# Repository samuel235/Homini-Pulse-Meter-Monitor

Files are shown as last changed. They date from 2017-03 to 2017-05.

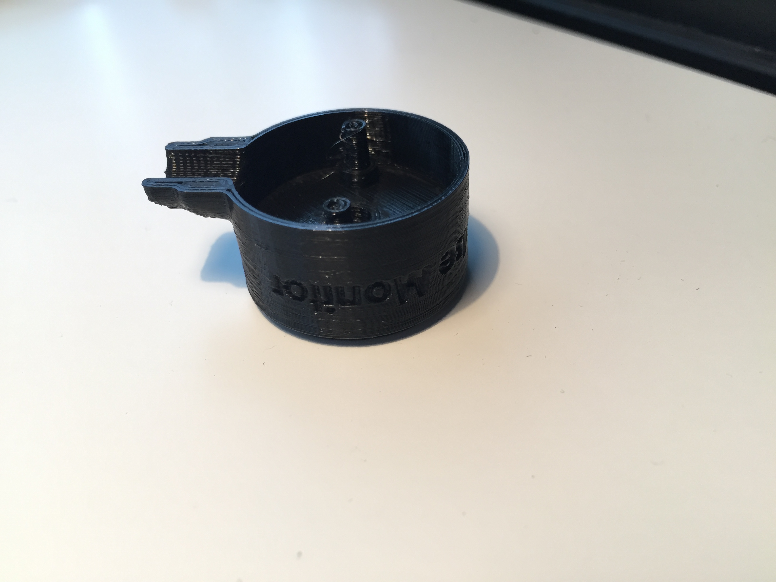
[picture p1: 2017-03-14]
sensor/images/3.jpeg

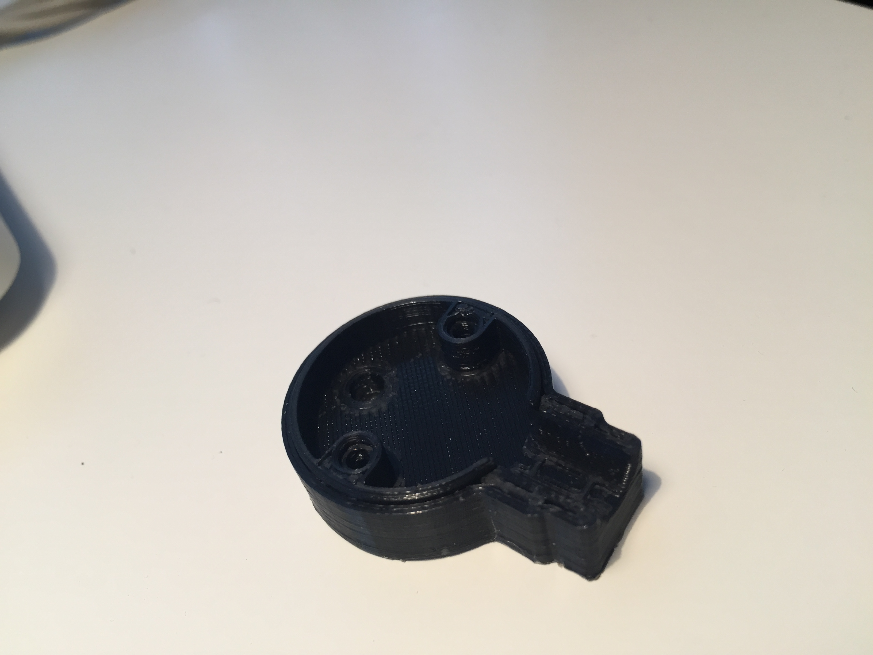
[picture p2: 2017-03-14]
sensor/images/1.jpeg

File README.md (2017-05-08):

# Homini Pulse Meter Monitor

## Brief Description
This ATMEGA328P based board has been created to enable wireless monitoring of your power meter. The product comprises of two parts, one sensor attachment and one custom ATMEGA328P board that the sensor connects to. Both parts are enclosed inside of their own 3D printed enclosures to ensure safety to the devices.

This device has been designed to be located directly on your power meter, the sensor is stuck to the front and the controller is enclosed off to the side of the meter, designed to stick to the side also with Velcro, but you can put it where you wish. The sensor module is attached to the Controller device via a micro USB connector but obviously this can be modified to suit your personal needs.

There is a footprint to allow the use of a AT25DF512C Flash IC to allow the use of OTA updates with MYSBootloader, please refer to the MYSBootloader documentation for the use of this feature to discover the needed fuses and process to install MYSBootloader itself. This enables you the option of updating the device for future software updates without physically getting to the device. We have also allowed the use of a ATSHA204 hardware signing by including a footprint for the ATSHA204 IC on the controller board.

## Function
- To monitor power usage of your home and report back to controller software for a visible display of your consumed electricity.

## Physical Dimensions
- Sensor: 36mm x 24mm x 33mm (Width x Length x Height)
- Controller: TBA

## Connectors
- FTDI and SPI for firmware upgrades
- Micro USB for Powering the device
- Micro USB for sensor connection

## Connections
#### Radio Frequency
Footprints for the following radios will be included.
- nRF24L01 Radio Transceiver
- RFM69 Radio Transceiver

## Power Supply
##### Either of the following:
- Micro USB wall charger.
- CR2450 Coin-cell battery.

## Software
#### Bootloader
- Mains Powered: [Gertsanders' bootloader](https://www.mysensors.org/about/bootloader) running at 16MHz External crystal.
- Battery Powered: [Gertsanders' bootloader](https://www.mysensors.org/about/bootloader) running at 8MHz Internal or External crystal.

If you would like to use OTA updates then please use [MYSBootloader](https://www.mysensors.org/about/ota)

#### Sketch

Will update sketches once I receive PCBs to test different variants of software out:

[Generic pulse sensor sketch Located here](https://www.mysensors.org/build/pulse_power), alternatively you can find customised sketches on my [github](https://github.com/samuel235/Homini-Pulse-Meter-Monitor) inside of the relevant folder to your build type.

## Testing
Testing will commence once boards have been received and assembled.

1. Controller board - Mains powered version - **COMPLETED**
2. Sensor board - Mains powered version - **COMPLETED**

## TO-DO List
1. Add battery monitoring circuitry for next version

## Update Log:
- Micro-Controller board designed (25/03/17)
- Sensor board designed (15/03/17)
- Sensor board (battery) designed (06/04/17)
- All boards ordered using [PCBWay](www.pcbway.com) (10/04/17)
- Board arrived and testing commenced (26/04/17)

## Issues
1. No issues reported at current date.

## Appreciations
Special thanks to:
1. Scalz from the MySensors community that has provided relevant design files and circuit schematics to aid in this product design. [MySensors](https://forum.mysensors.org/user/scalz)/[github](https://github.com/scalz)
2. [Mysensors.org](Mysensors.org)
3. [Openhardware.org](Openhardware.org)
4. [Sparkfun](sparkfun.com) and [Adafruit](adafruit.com) for their parts library for Eagle

If you have any suggestions, please add to the forum post over at [MySensors forum post](https://forum.mysensors.org/topic/6460/homini-pulse-meter-monitor)

I'm very interested in all of your variations, improvements and applications of this module, please add them to the comments with pictures and/or Videos.

## Disclaimer
**_I do not advise you in any way to make/install this product into a property and therefore I take no responsibility for any issues, problems you have or even health implications that you endure while completing the installation or even using the product after installing. BUILD, USE and INSTALL AT YOUR OWN RISK_**

## Licensing
This product is licensed under the CC-BY-SA OpenHardware certificate. For more information please see https://creativecommons.org/licenses/by-sa/4.0/

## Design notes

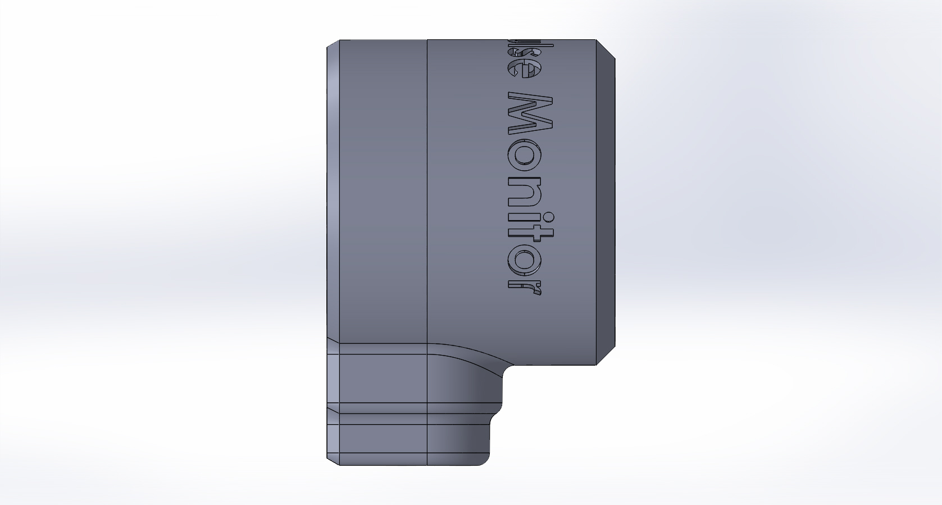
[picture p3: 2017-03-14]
sensor/images/View3.JPG

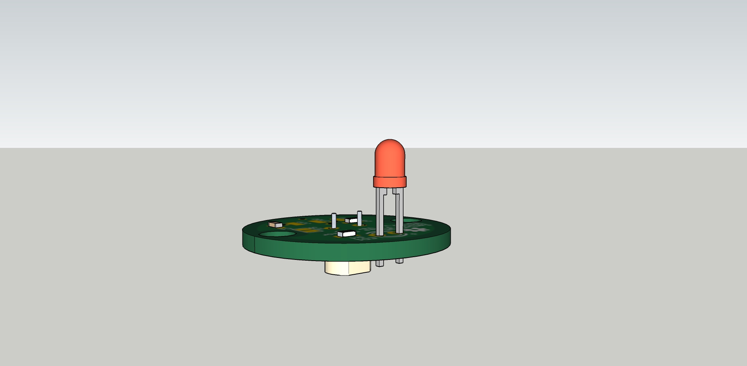
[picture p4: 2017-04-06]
sensorbatt/images/SensorBatt_PCB_3.jpg

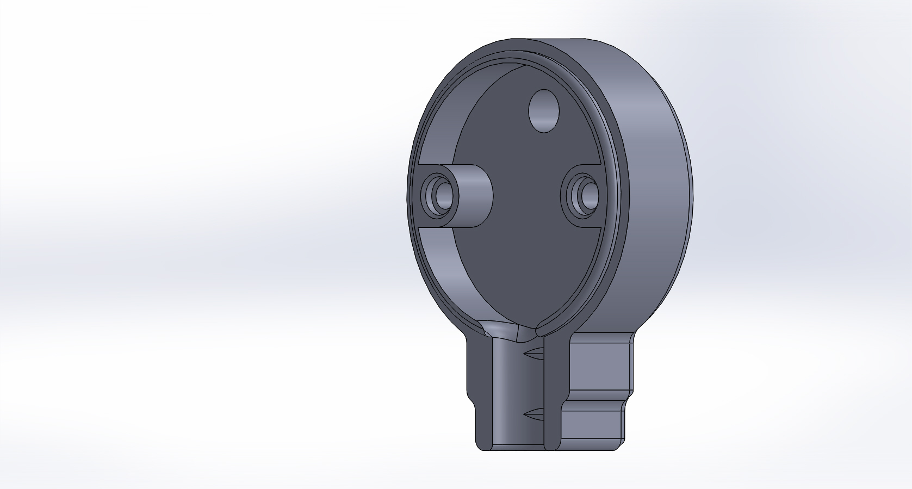
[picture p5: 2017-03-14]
sensor/images/View8.JPG

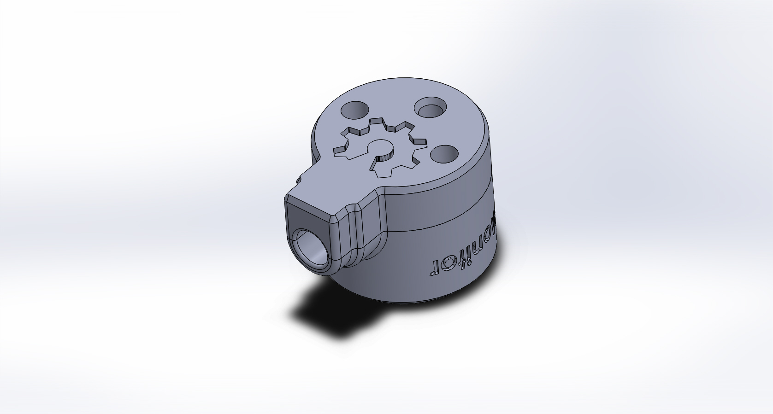
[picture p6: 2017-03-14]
sensor/images/View1.JPG

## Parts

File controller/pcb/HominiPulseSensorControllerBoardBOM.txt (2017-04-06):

Partlist exported from M:/My Documents/eagle/Home Automation/Homini Pulse Meter Module/Ver1/ControllerBoard.sch at 05/04/2017 18:26

Part Value                 Device                    Package                  Description                                                                                                     PROD_ID    VALUE          
BT1  CR2450                CR2450                    BATTCON_24.5MM                                                                                                                                                     
C1   0.1uF                 C-EUC0603                 C0603                    CAPACITOR, European symbol                                                                                                                
C2   0.1uF                 C-EUC0603                 C0603                    CAPACITOR, European symbol                                                                                                                
C4   0.1uF                 C-EUC0603                 C0603                    CAPACITOR, European symbol                                                                                                                
C5   22pF                  C-EUC0603                 C0603                    CAPACITOR, European symbol                                                                                                                
C6   22pF                  C-EUC0603                 C0603                    CAPACITOR, European symbol                                                                                                                
C7   0.1uF                 C-EUC0603                 C0603                    CAPACITOR, European symbol                                                                                                                
C8   0.1uF                 C-EUC0603                 C0603                    CAPACITOR, European symbol                                                                                                                
C9   0.1uF                 C-EUC0603                 C0603                    CAPACITOR, European symbol                                                                                                                
C10  0.1uF                 C-EUC0603                 C0603                    CAPACITOR, European symbol                                                                                                                
C11  10uF                  C-EUC0603                 C0603                    CAPACITOR, European symbol                                                                                                                
C12  0.1uF                 C-EUC0603                 C0603                    CAPACITOR, European symbol                                                                                                                
C13  4.7uF                 C-EUC0603                 C0603                    CAPACITOR, European symbol                                                                                                                
C15  0.1uF                 C-EUC0603                 C0603                    CAPACITOR, European symbol                                                                                                                
D1   Ext Pwr               LED3MM                    LED3MM                   LED                                                                                                                                       
D2   Red                   LED3MM                    LED3MM                   LED                                                                                                                                       
D3   Yellow                LED3MM                    LED3MM                   LED                                                                                                                                       
D4   Green                 LED3MM                    LED3MM                   LED                                                                                                                                       
J1                         CONN_03                   1X03                     Multi connection point. Often used as Generic Header-pin footprint for 0.1 inch spaced/style header connections                           
J2   SPI_Prog              AVR_SPI_PROG_3X2PTH       2X3                      AVR ISP 6 Pin                                                                                                                             
J3   FTDI_Prog             CONN_06NO_SILK_FEMALE_PTH 1X06_NO_SILK             Multi connection point. Often used as Generic Header-pin footprint for 0.1 inch spaced/style header connections CONN-08437                
JP1  PWRUSB                MICROUSBSMD               MICROUSBSMD                                                                                                                                                        
JP2  SENSOR                MICROUSBSMD               MICROUSBSMD                                                                                                                                                        
M1   WIRELESS-NRF24L01SMD2 WIRELESS-NRF24L01SMD2     WIRELESS-NRF24L01-SMD-2  2.4 GHz Wireless Module based on NRF24L01 chip                                                                                            
R1   56K                   R-EU_R0603                R0603                    RESISTOR, European symbol                                                                                                                 
R2   1K                    R-EU_R0603                R0603                    RESISTOR, European symbol                                                                                                                 
R3   10K                   R-EU_R0603                R0603                    RESISTOR, European symbol                                                                                                                 
R4   180R                  R-EU_R0603                R0603                    RESISTOR, European symbol                                                                                                                 
R5   100R                  R-EU_R0603                R0603                    RESISTOR, European symbol                                                                                                                 
R6   100R                  R-EU_R0603                R0603                    RESISTOR, European symbol                                                                                                                 
R7   100R                  R-EU_R0603                R0603                    RESISTOR, European symbol                                                                                                                 
R8   1M                    R-EU_R0603                R0603                    RESISTOR, European symbol                                                                                                                 
R9   470K                  R-EU_R0603                R0603                    RESISTOR, European symbol                                                                                                                 
SW1  RESET                 SMD5X5X1.5MM              SMD5X5X1.5MM                                                                                                                                                       
U1   AT25DF512C            AT25DF512C                SOIC-8                                                                                                                                                             
U2   ATMEGA328P_TQFP       ATMEGA328P_TQFP           TQFP32-08                Popular 328P in QFP                                                                                             IC-09069   ATMEGA328P_TQFP
U3                         LD1117V33                 SOC-223                                                                                                                                                            
U4   ATSHA204A             ATSHA204A                 SOT23                                                                                                                                                              
U5   RFM95W                WIRELESS-LORA-RFM95W#SMD  WIRELESS-LORA-RFM95W#SMD 868/915 MHz LoRa Radio Transceiver Module based on SX1276 chip                                                                            
X1   8Mhz                  HC-49S-SMT                HC-49S-SMT

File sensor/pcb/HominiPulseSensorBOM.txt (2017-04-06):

Part  Value      Device       Package      Description                                 
5V               SMD2         SMD1,27-2,54 SMD PAD                                     
C1    0.1uF      C-EUC0603    C0603        CAPACITOR, European symbol                  
D1    PD204-6C   PD204-6C     3MM-PTH                                                  
DOUT             SMD2         SMD1,27-2,54 SMD PAD                                     
GND              SMD2         SMD1,27-2,54 SMD PAD                                     
IC1   LM393D     LM393D       SO08         COMPARATOR                                  
LED1  Red        LED3MM       LED3MM       LED                                         
LOGO1 OSHW-LOGOS OSHW-LOGOS   OSHW-LOGO-S  Open-Source Hardware (OSHW) Logo            
R1    33k        R-EU_R0603   R0603        RESISTOR, European symbol                   
R2    180R       R-EU_R0603   R0603        RESISTOR, European symbol                   
TM1   10k        TRIMPOTTC33X TC33X        SMT trimmer potentiometer part number TC33X

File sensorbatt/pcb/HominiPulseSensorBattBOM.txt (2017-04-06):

Part  Value      Device     Package      Description                      
C1    0.1uF      C-EUC0603  C0603        CAPACITOR, European symbol       
DOUT             SMD2       SMD1,27-2,54 SMD PAD                          
GND              SMD2       SMD1,27-2,54 SMD PAD                          
LED1  Red        LED3MM     LED3MM       LED                              
LOGO1 OSHW-LOGOS OSHW-LOGOS OSHW-LOGO-S  Open-Source Hardware (OSHW) Logo 
Q1    BS250SMD   BS250SMD   SOT23        P-CHANNEL MOS FET                
R1    330K       R-EU_R0603 R0603        RESISTOR, European symbol        
R2    100K       R-EU_R0603 R0603        RESISTOR, European symbol        
R3    470K       R-EU_R0603 R0603        RESISTOR, European symbol        
R4    1K5        R-EU_R0603 R0603        RESISTOR, European symbol        
R5    5549-LDR   5549-LDR   LDR-PTH                                       
SJ1              SJ         SJ           SMD solder JUMPER                
VCC              SMD2       SMD1,27-2,54 SMD PAD

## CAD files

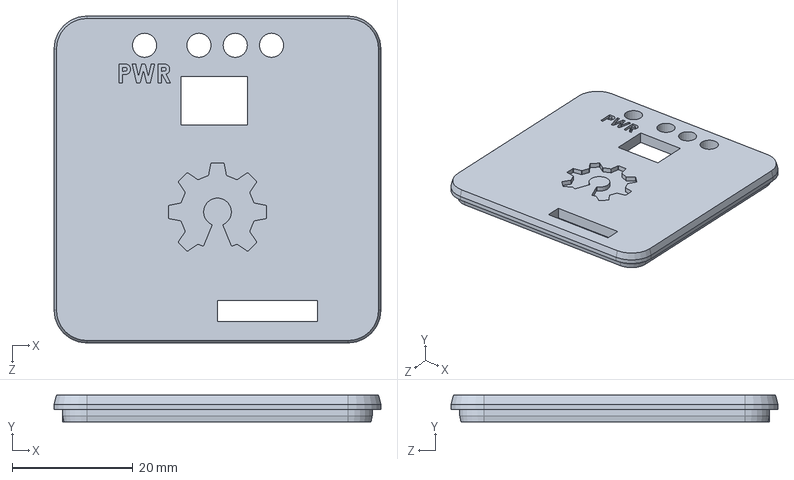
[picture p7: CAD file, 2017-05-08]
controller/enclosure/HominiPulseSensorControllerEnclosure.SLDPRT
54.1 x 4.40 x 54.1 mm

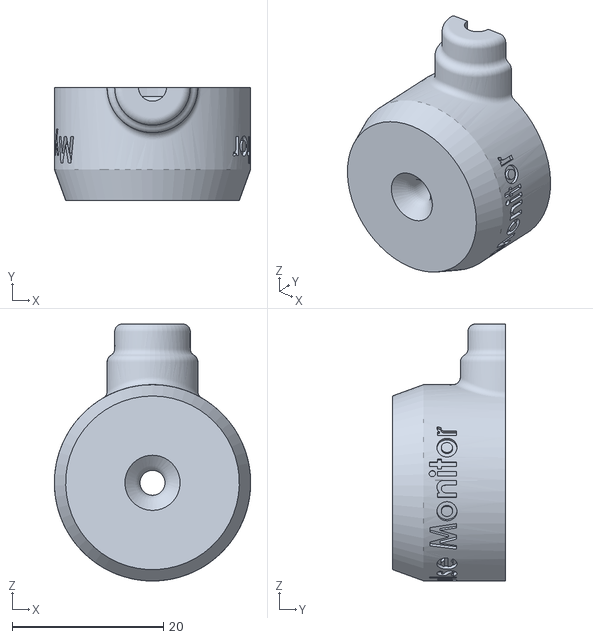
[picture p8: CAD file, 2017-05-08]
sensor/enclosure/Bottom.STL
26.0 x 15.0 x 34.0

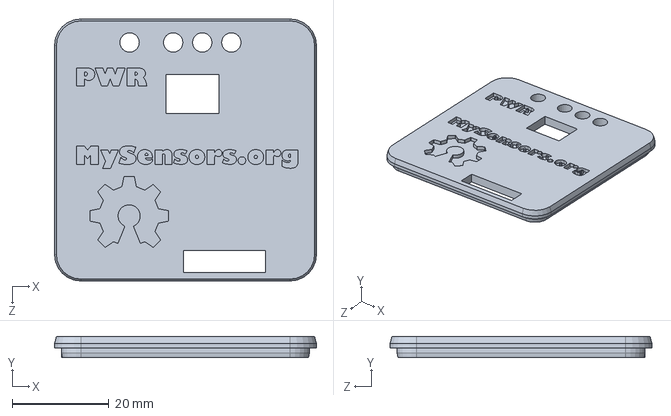
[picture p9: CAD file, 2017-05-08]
controller/enclosure/HominiPulseSensorControllerEnclosure3.SLDPRT
54.1 x 4.40 x 54.1 mm

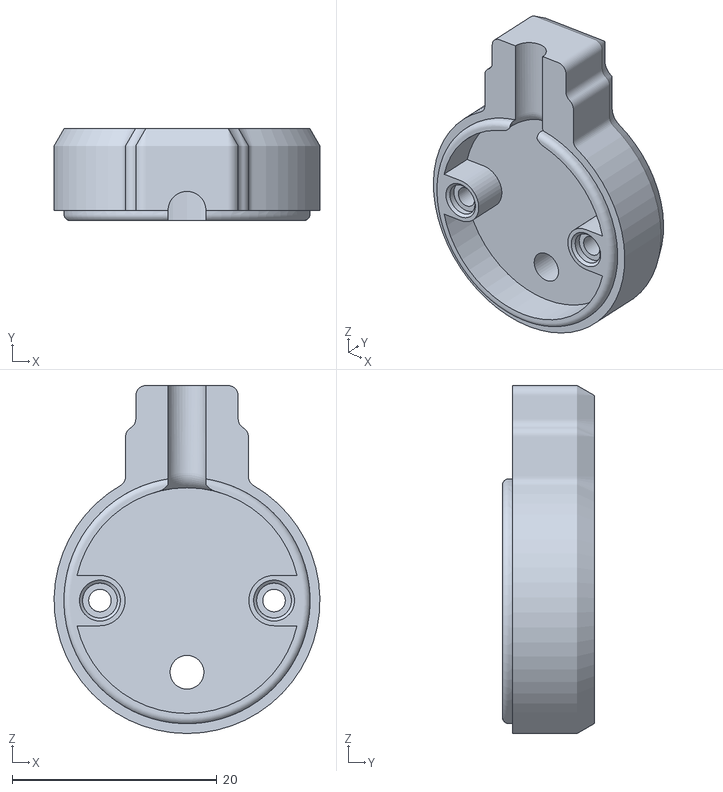
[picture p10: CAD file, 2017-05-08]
sensor/enclosure/Top.STL
26.0 x 9.00 x 34.0

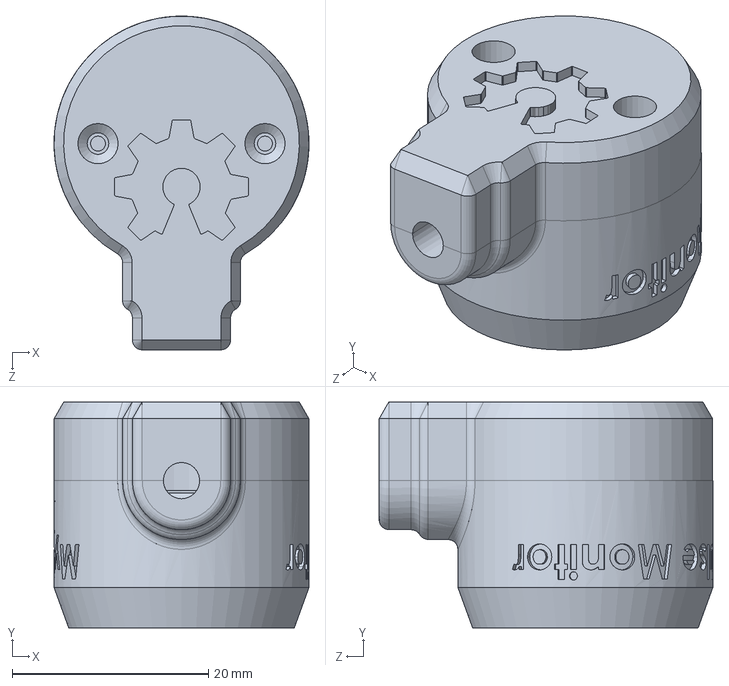
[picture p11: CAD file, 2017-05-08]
sensorbatt/enclosure/Part1.SLDPRT
26.0 x 23.0 x 34.0 mm

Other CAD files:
sensorbatt/enclosure/Bottom.STL
sensorbatt/enclosure/Top.STL
controller/enclosure/Top3.STL
sensor/enclosure/Part1.SLDPRT
controller/enclosure/Top2.STL
controller/enclosure/Top.STL
controller/enclosure/HominiPulseSensorControllerEnclosure.STL
controller/sketchUp/controller_PCB.skp
sensor/sketchup/HominiPulseSensor.skp
sensorbatt/Sketchup/HominiPulseSensorBatt.skp

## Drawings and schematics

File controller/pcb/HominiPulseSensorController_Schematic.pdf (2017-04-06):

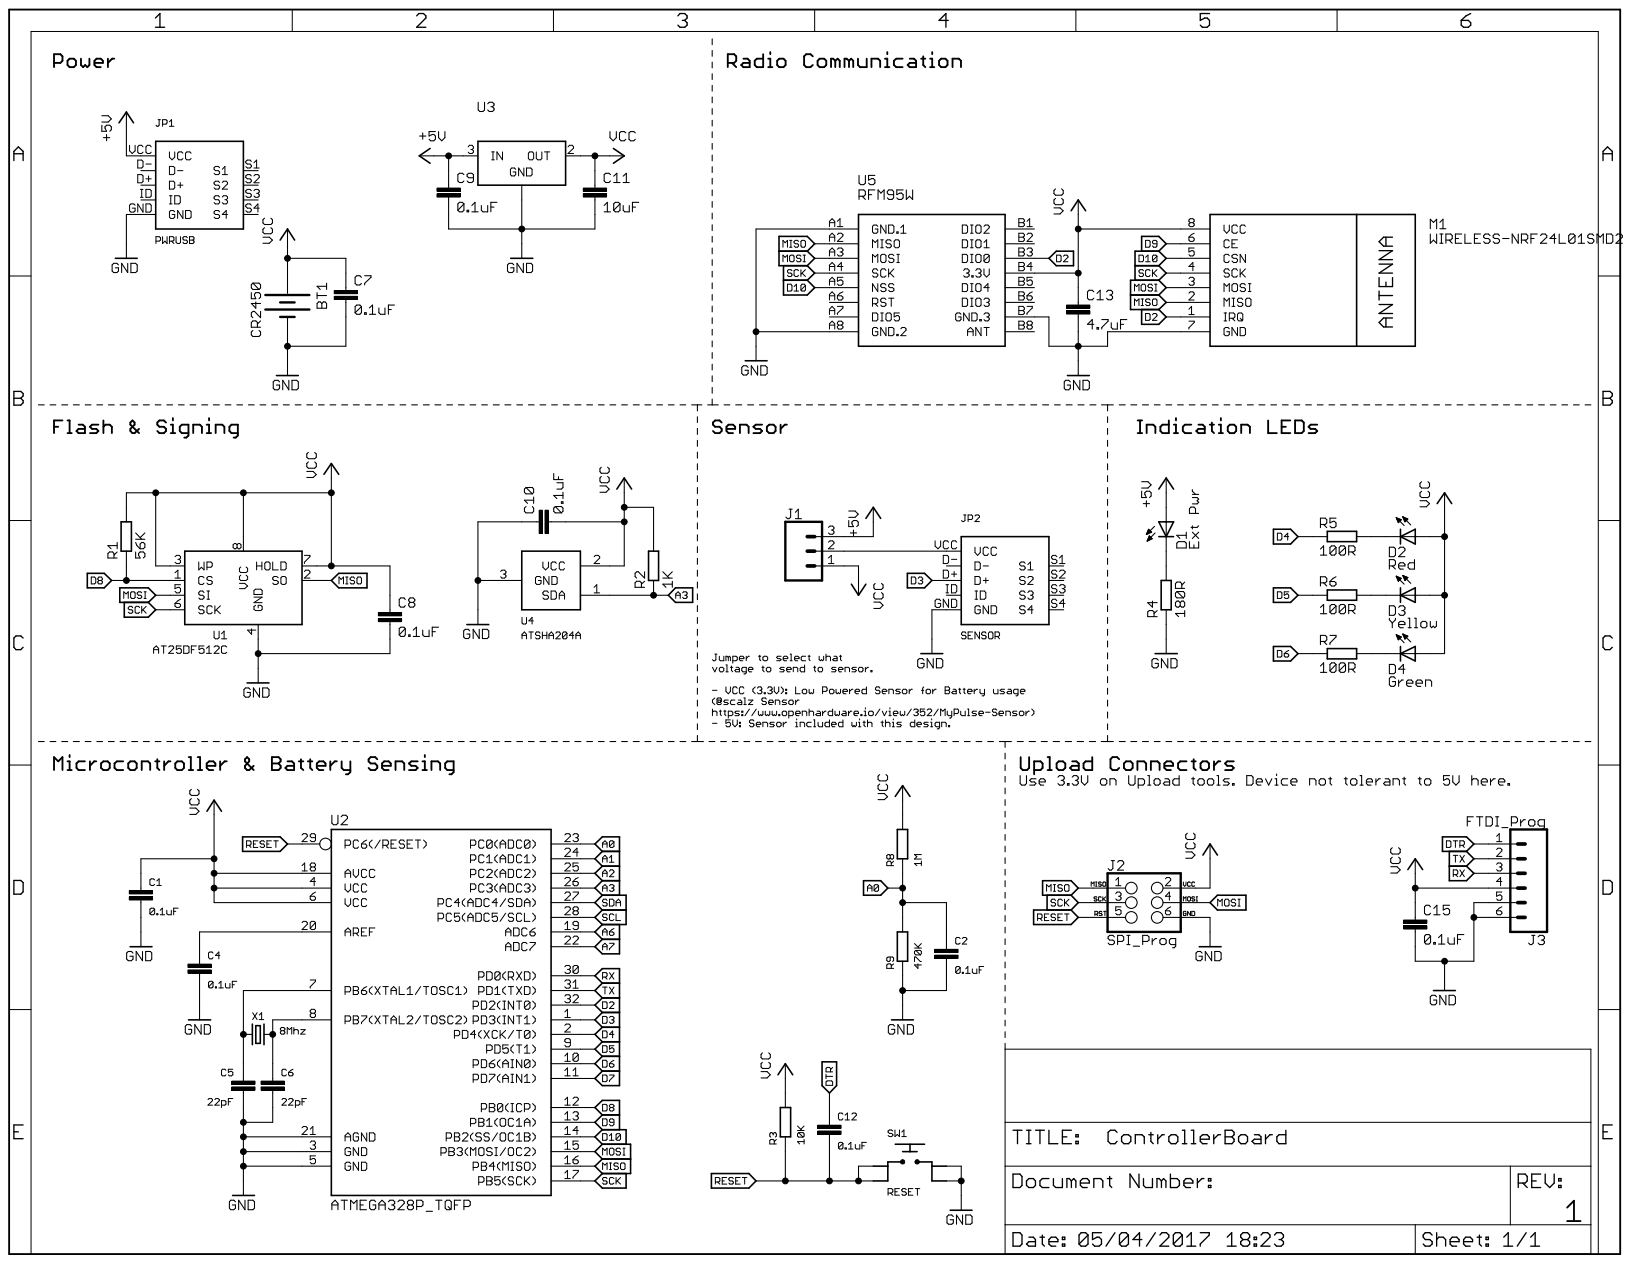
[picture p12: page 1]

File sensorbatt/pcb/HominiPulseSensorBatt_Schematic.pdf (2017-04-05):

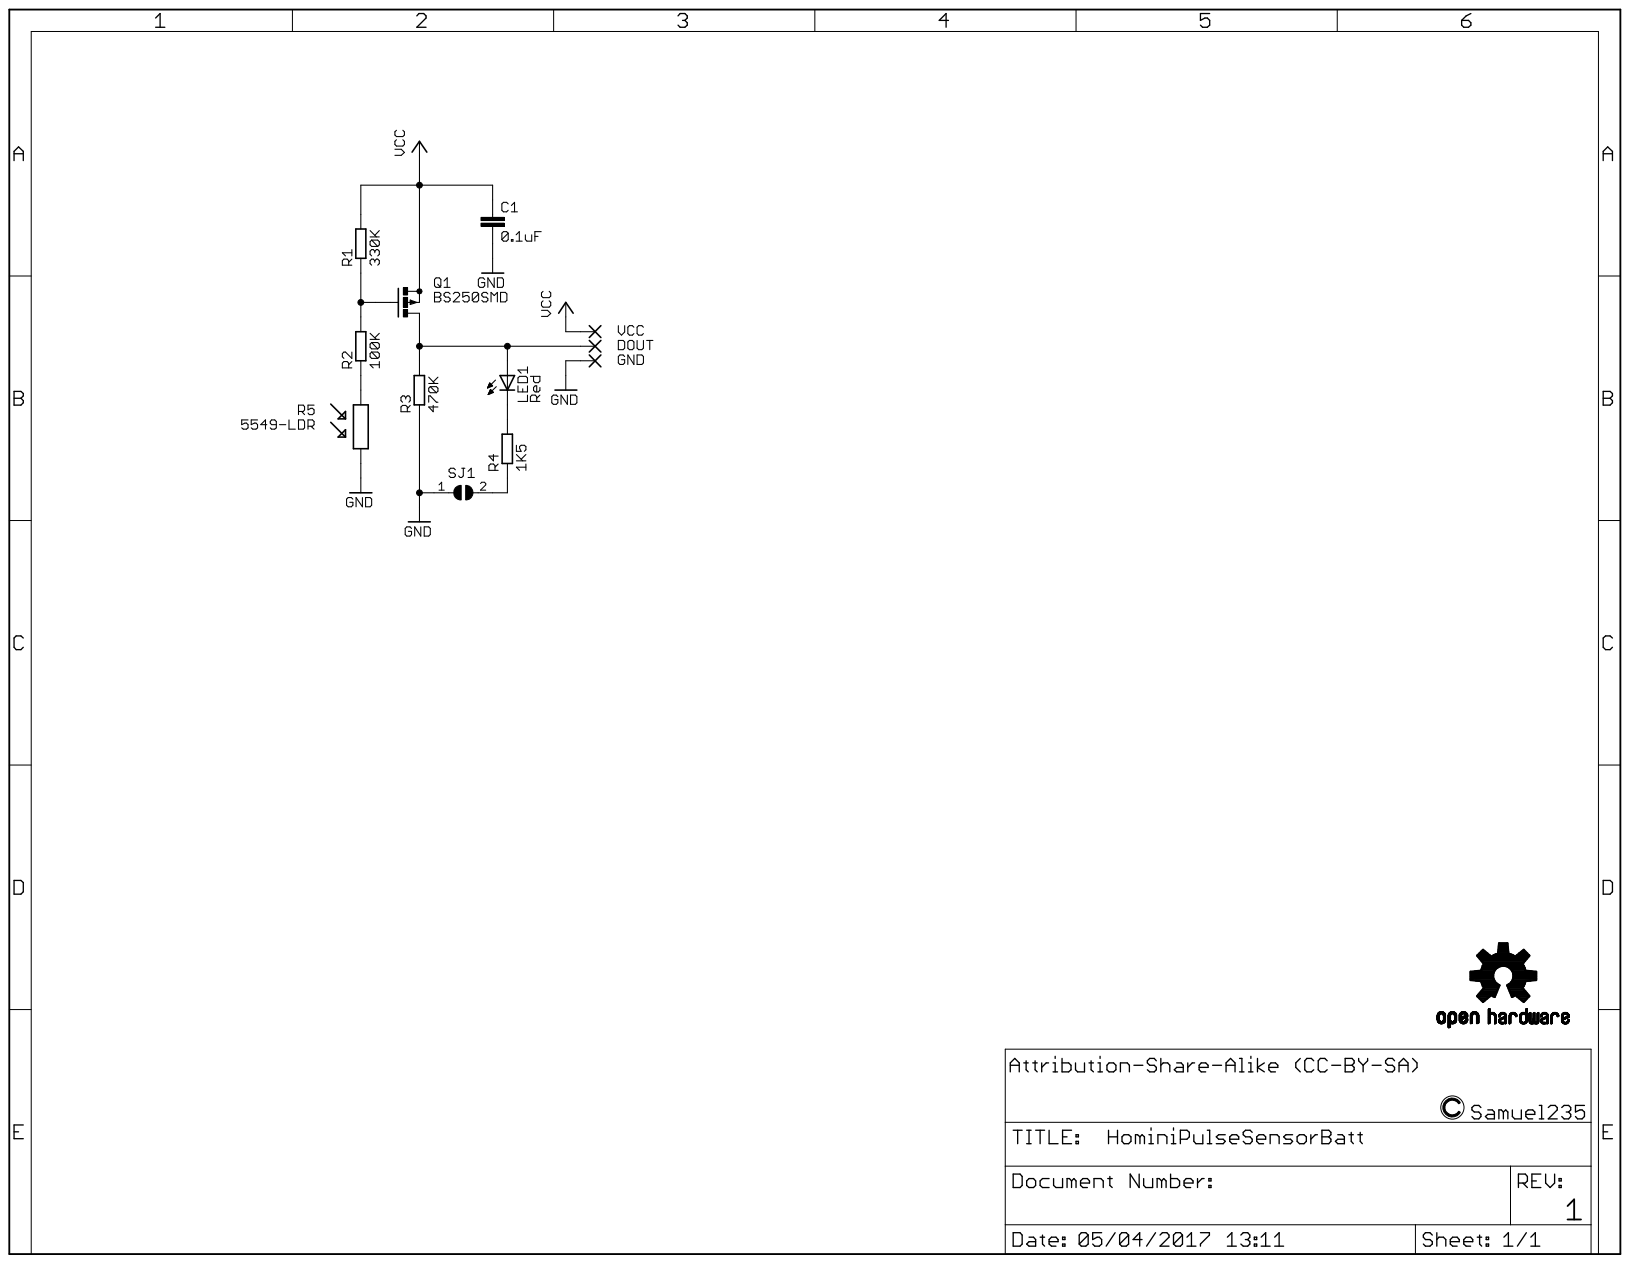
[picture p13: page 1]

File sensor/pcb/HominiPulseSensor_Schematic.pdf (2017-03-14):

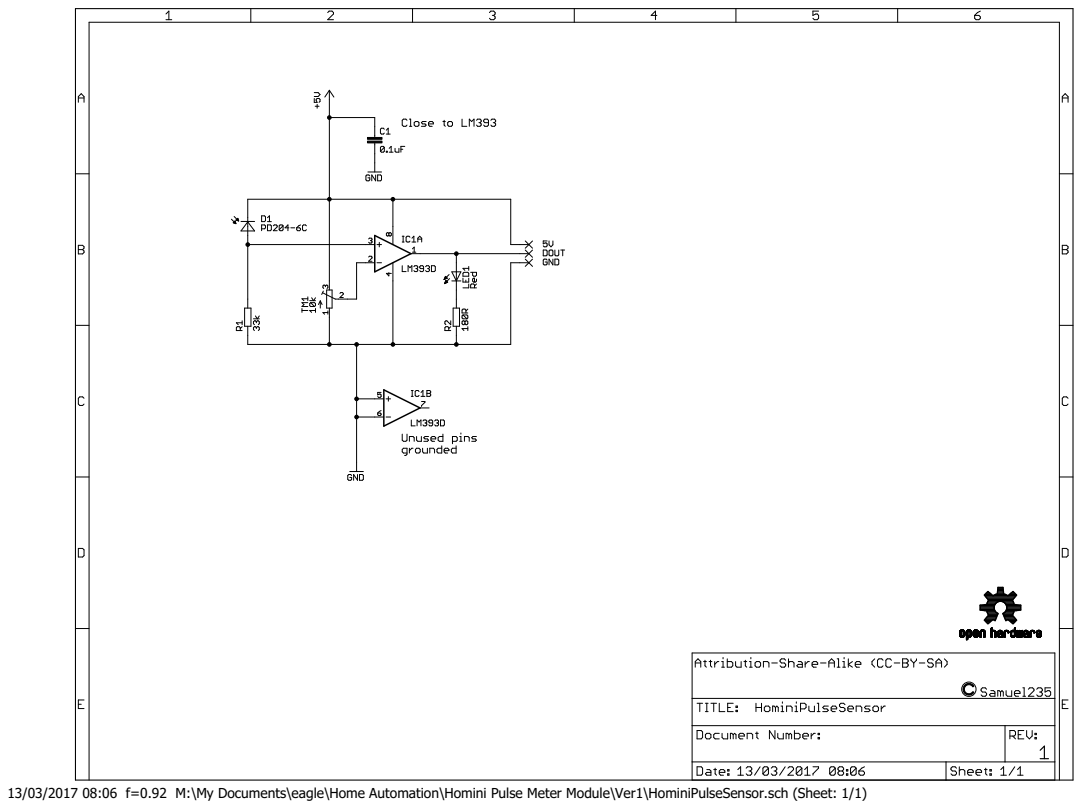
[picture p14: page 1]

13/03/2017 08:06 f=0.92 M:\My Documents\eagle\Home Automation\Homini Pulse Meter Module\Ver1\HominiPulseSensor.sch (Sheet: 1/1)

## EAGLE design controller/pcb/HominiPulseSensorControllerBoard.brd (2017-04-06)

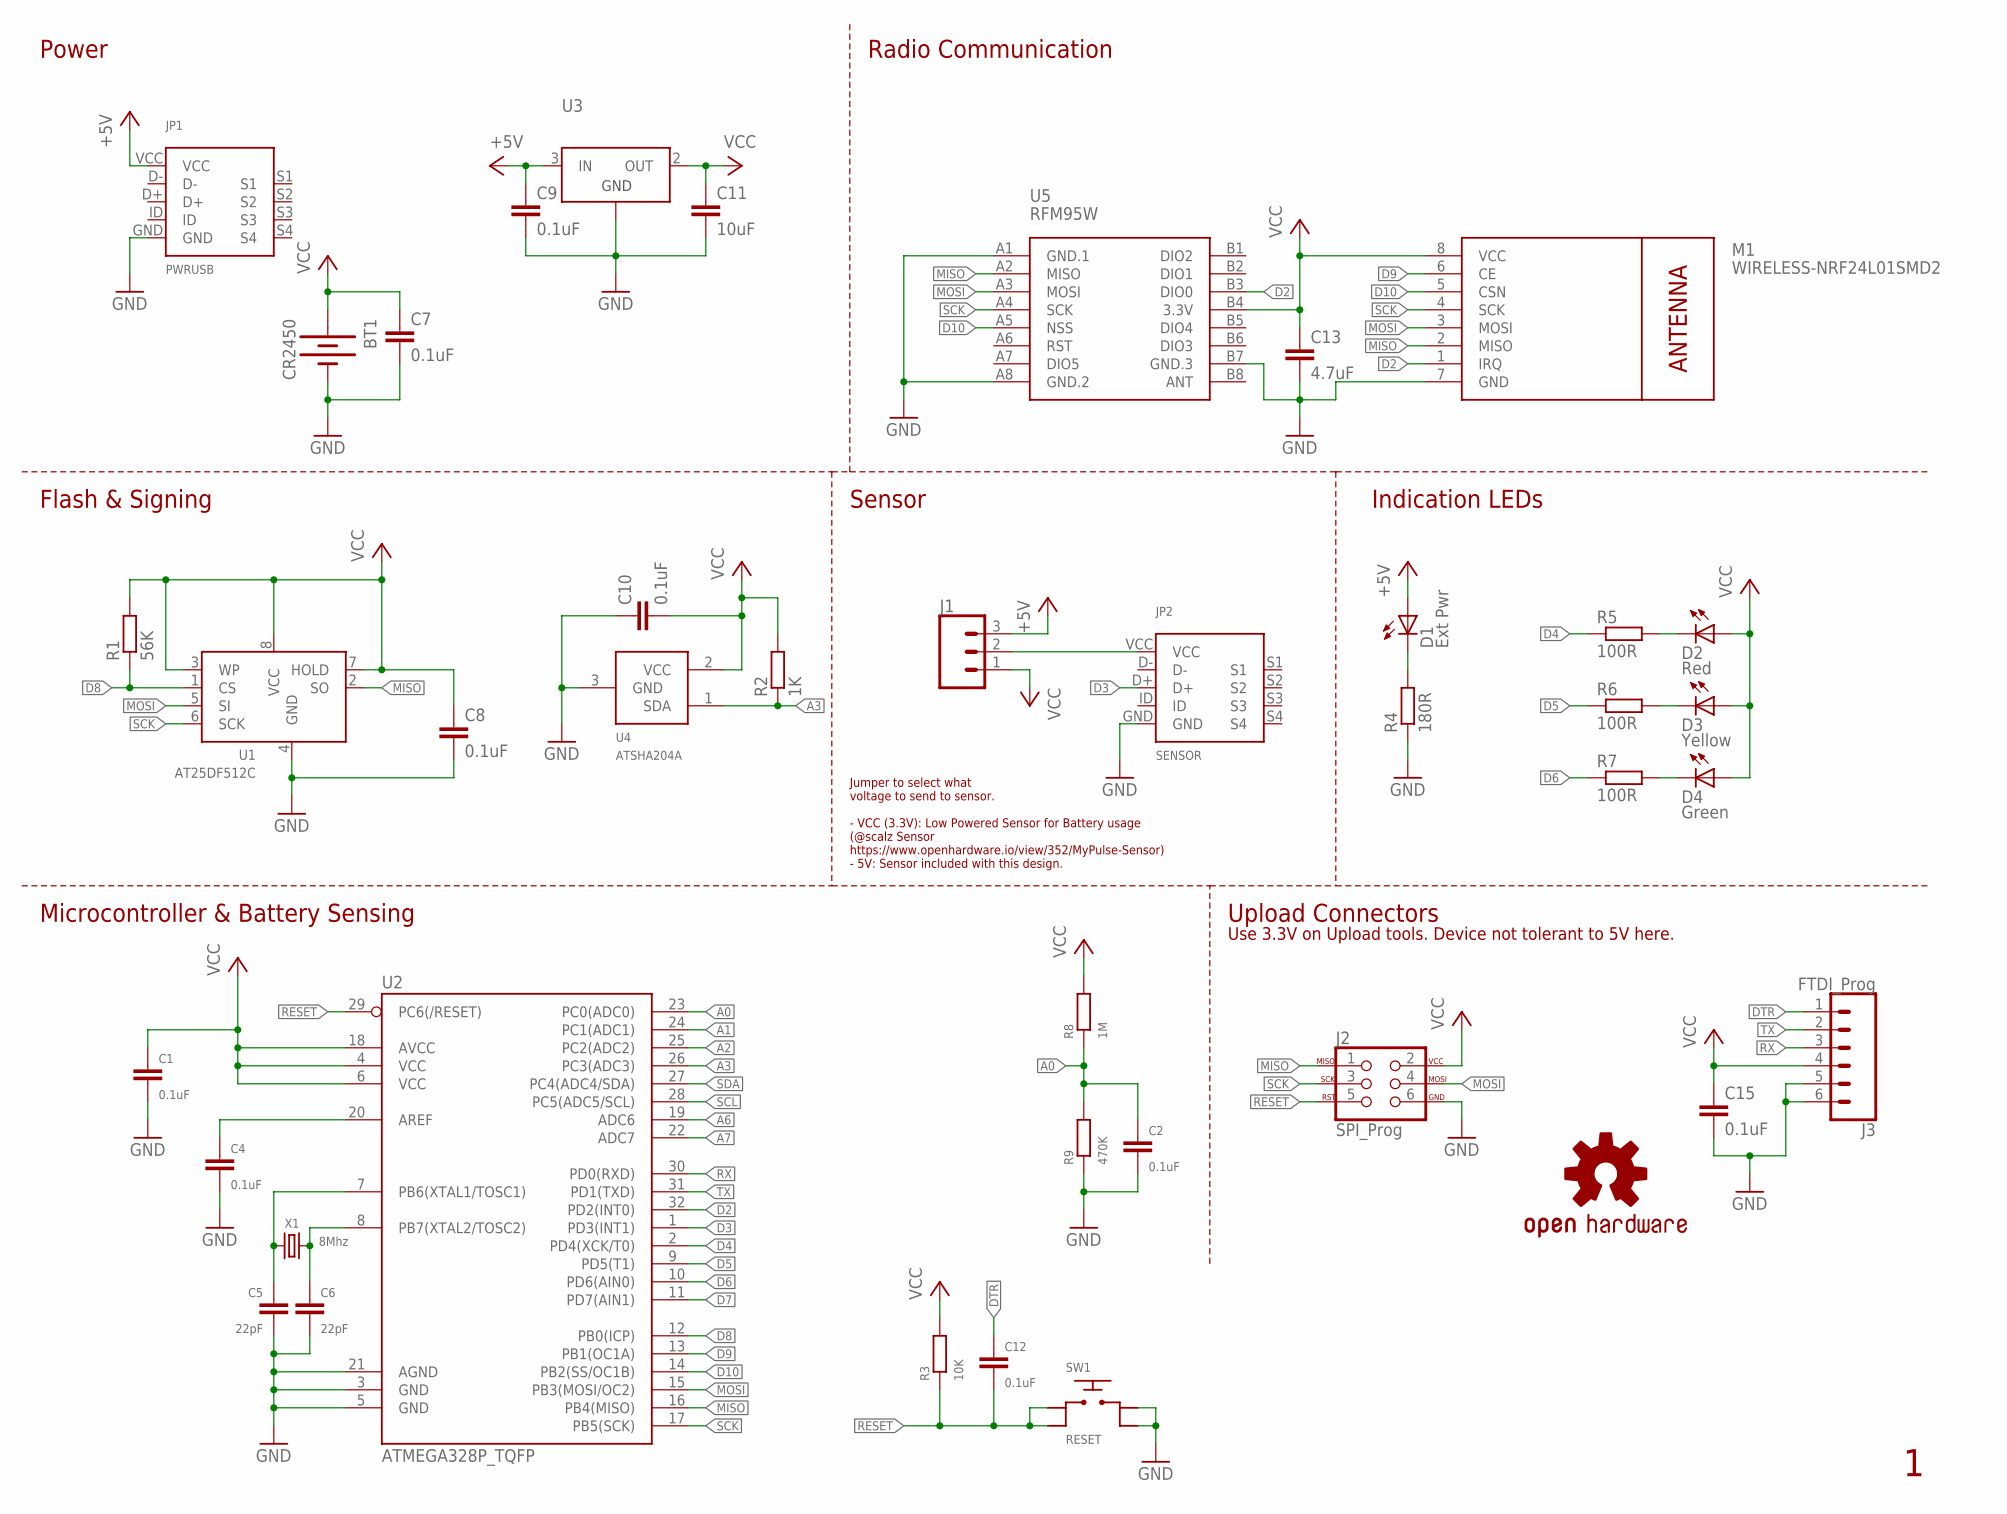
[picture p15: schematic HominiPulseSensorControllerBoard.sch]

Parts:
BT1: CR2450; BATTCON_24.5MM
C1, C2, C4, C7, C8, C9, C10, C12, C15: 0.1uF; C0603
C5, C6: 22pF; C0603
C11: 10uF; C0603
C13: 4.7uF; C0603
D1: Ext Pwr; LED3MM
D2: Red; LED3MM
D3: Yellow; LED3MM
D4: Green; LED3MM
J1: CONN_03; 1X03
J2: SPI_Prog; 2X3
J3: FTDI_Prog; 1X06_NO_SILK
JP1: PWRUSB; MICROUSBSMD
JP2: SENSOR; MICROUSBSMD
LOGO1: OSHW-LOGOM; OSHW-LOGO-M
M1: WIRELESS-NRF24L01SMD2; WIRELESS-NRF24L01-SMD-2
R1: 56K; R0603
R2: 1K; R0603
R3: 10K; R0603
R4: 180R; R0603
R5, R6, R7: 100R; R0603
R8: 1M; R0603
R9: 470K; R0603
SW1: RESET; SMD5X5X1.5MM
U1: AT25DF512C; SOIC-8
U2: ATMEGA328P_TQFP; TQFP32-08
U3: LD1117V33; SOC-223
U4: ATSHA204A; SOT23
U5: RFM95W; WIRELESS-LORA-RFM95W#SMD
X1: 8Mhz; HC-49S-SMT

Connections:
+5V: C9.1, D1.A, J1.3, JP1.VCC, U3.3 (IN)
A0: C2.1, R8.1, R9.2, U2.23 (PC0(ADC0))
A1: U2.24 (PC1(ADC1))
A2: U2.25 (PC2(ADC2))
A3: R2.1, U2.26 (PC3(ADC3)), U4.1 (SDA)
A6: U2.19 (ADC6)
A7: U2.22 (ADC7)
D2: M1.1 (IRQ), U2.32 (PD2(INT0)), U5.B3 (DIO0)
D3: JP2.D+, U2.1 (PD3(INT1))
D4: R5.1, U2.2 (PD4(XCK/T0))
D5: R6.1, U2.9 (PD5(T1))
D6: R7.1, U2.10 (PD6(AIN0))
D7: U2.11 (PD7(AIN1))
D8: R1.1, U1.1 (CS), U2.12 (PB0(ICP))
D9: M1.6 (CE), U2.13 (PB1(OC1A))
D10: M1.5 (CSN), U2.14 (PB2(SS/OC1B)), U5.A5 (NSS)
DTR: C12.1, J3.1
GND: BT1.2 (-), C1.2, C2.2, C4.2, C5.2, C6.2, C7.2, C8.2, C9.2, C10.1, C11.2, C13.2, C15.2, J2.6, J3.5, J3.6, JP1.GND, JP2.GND, M1.7 (GND), R4.1, R9.1, SW1.3, SW1.4, U1.4 (GND), U2.3 (GND), U2.5 (GND), U2.21 (AGND), U3.1 (GND), U4.3 (GND), U5.A1 (GND.1), U5.A8 (GND.2), U5.B7 (GND.3)
MISO: J2.1, M1.2 (MISO), U1.2 (SO), U2.16 (PB4(MISO)), U5.A2 (MISO)
MOSI: J2.4, M1.3 (MOSI), U1.5 (SI), U2.15 (PB3(MOSI/OC2)), U5.A3 (MOSI)
unnamed: C6.1, U2.8 (PB7(XTAL2/TOSC2)), X1.1
unnamed: C5.1, U2.7 (PB6(XTAL1/TOSC1)), X1.2
unnamed: C4.1, U2.20 (AREF)
unnamed: J1.2, JP2.VCC
unnamed: D1.K (C), R4.2
unnamed: D2.K (C), R5.2
unnamed: D3.K (C), R6.2
unnamed: D4.K (C), R7.2
RESET: C12.2, J2.5, R3.1, SW1.1, SW1.2, U2.29 (PC6(/RESET))
RX: J3.3, U2.30 (PD0(RXD))
SCK: J2.3, M1.4 (SCK), U1.6 (SCK), U2.17 (PB5(SCK)), U5.A4 (SCK)
SCL: U2.28 (PC5(ADC5/SCL))
SDA: U2.27 (PC4(ADC4/SDA))
TX: J3.2, U2.31 (PD1(TXD))
VCC: BT1.1 (+), C1.1, C7.1, C8.1, C10.2, C11.1, C13.1, C15.1, D2.A, D3.A, D4.A, J1.1, J2.2, J3.4, M1.8 (VCC), R1.2, R2.2, R3.2, R8.2, U1.3 (WP), U1.7 (HOLD), U1.8 (VCC), U2.4 (VCC), U2.6 (VCC), U2.18 (AVCC), U3.2 (OUT), U4.2 (VCC), U5.B4 (3.3V)

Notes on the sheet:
Jumper to select what voltage to send to sensor. - VCC (3.3V): Low Powered Sensor for Battery usage (@scalz Sensor https://www.openhardware.io/view/352/MyPulse-Sensor) - 5V: Sensor included with this design.
Upload Connectors
Microcontroller & Battery Sensing
Power
Flash & Signing
Sensor
Indication LEDs
Radio Communication
Use 3.3V on Upload tools. Device not tolerant to 5V here.

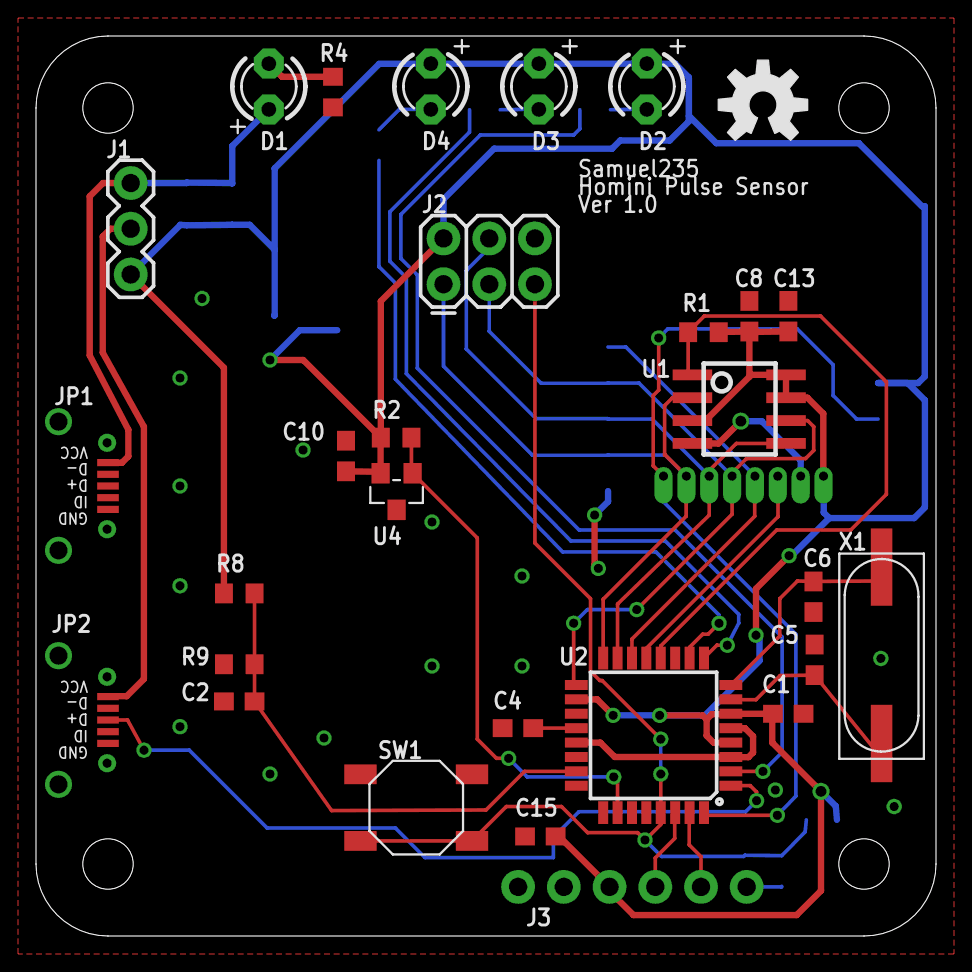
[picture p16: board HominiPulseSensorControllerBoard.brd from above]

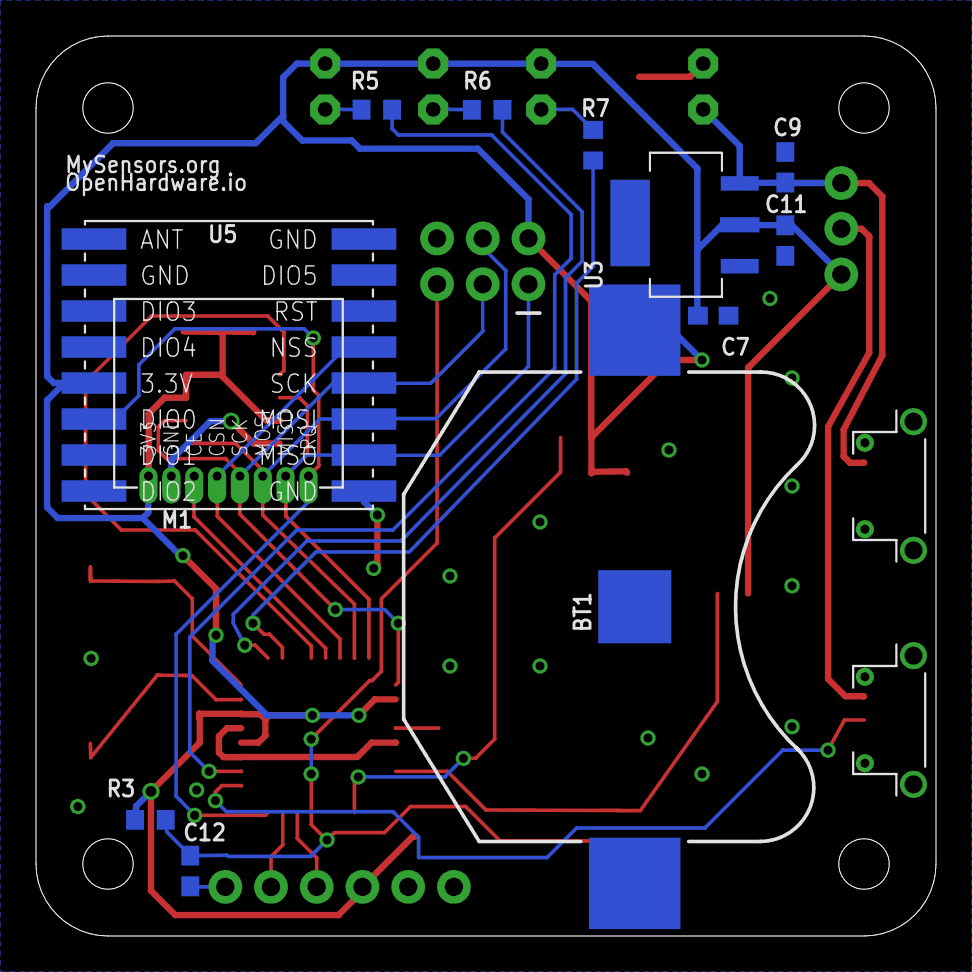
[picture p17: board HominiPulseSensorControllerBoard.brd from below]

Board: 2 copper layers, 50.0 x 50.0 mm, 41 parts (12 on the bottom side), 28 nets.

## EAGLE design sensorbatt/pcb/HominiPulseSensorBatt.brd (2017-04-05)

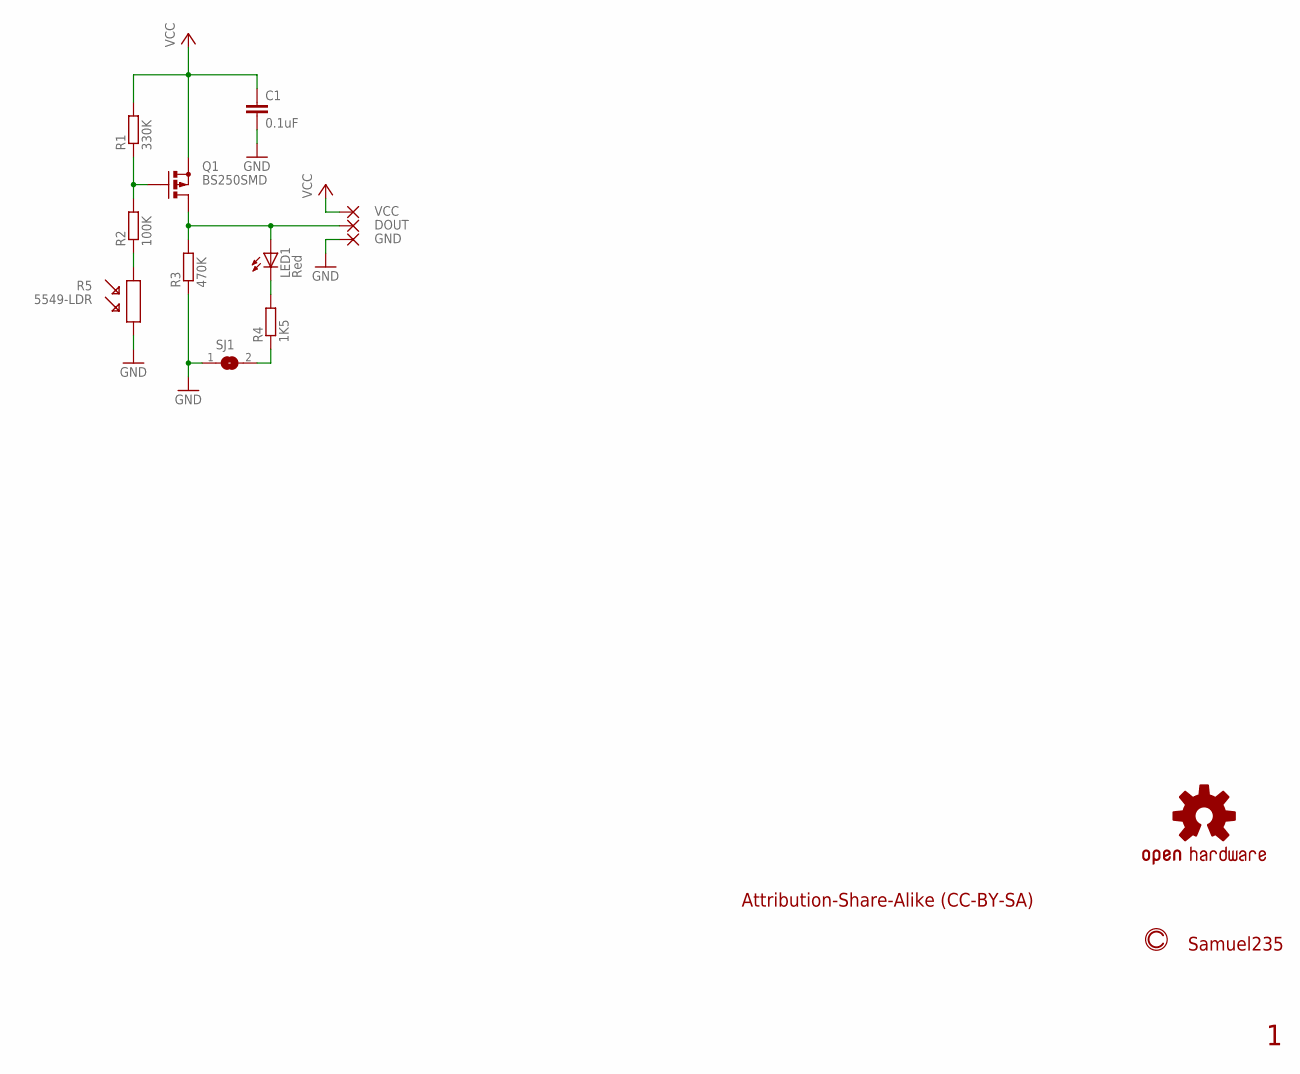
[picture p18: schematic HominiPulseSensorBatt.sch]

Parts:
C1: 0.1uF; C0603
DOUT: SMD2; SMD1,27-2,54
GND: SMD2; SMD1,27-2,54
LED1: Red; LED3MM
LOGO1: OSHW-LOGOS; OSHW-LOGO-S
Q1: BS250SMD; SOT23
R1: 330K; R0603
R2: 100K; R0603
R3: 470K; R0603
R4: 1K5; R0603
R5: 5549-LDR; LDR-PTH
SJ1: SJ
VCC: SMD2; SMD1,27-2,54

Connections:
GND: C1.2, GND.1, R3.1, R5.1, SJ1.1
unnamed: Q1.1 (G), R1.1, R2.2
unnamed: R2.1, R5.2
unnamed: DOUT.1, LED1.A, Q1.3 (D), R3.2
unnamed: R4.1, SJ1.2
unnamed: LED1.K (C), R4.2
VCC: C1.1, Q1.2 (S), R1.2, VCC.1

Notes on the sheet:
Samuel235
Attribution-Share-Alike (CC-BY-SA)

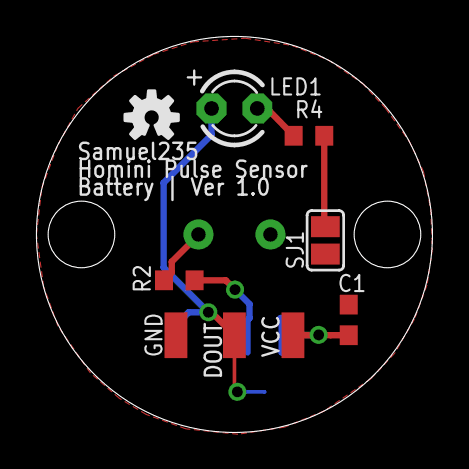
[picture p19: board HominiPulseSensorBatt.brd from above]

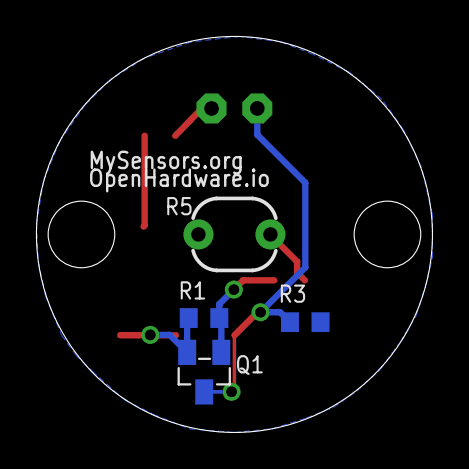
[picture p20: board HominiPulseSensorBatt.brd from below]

Board: 2 copper layers, 22.0 x 22.0 mm, 13 parts (4 on the bottom side), 7 nets.

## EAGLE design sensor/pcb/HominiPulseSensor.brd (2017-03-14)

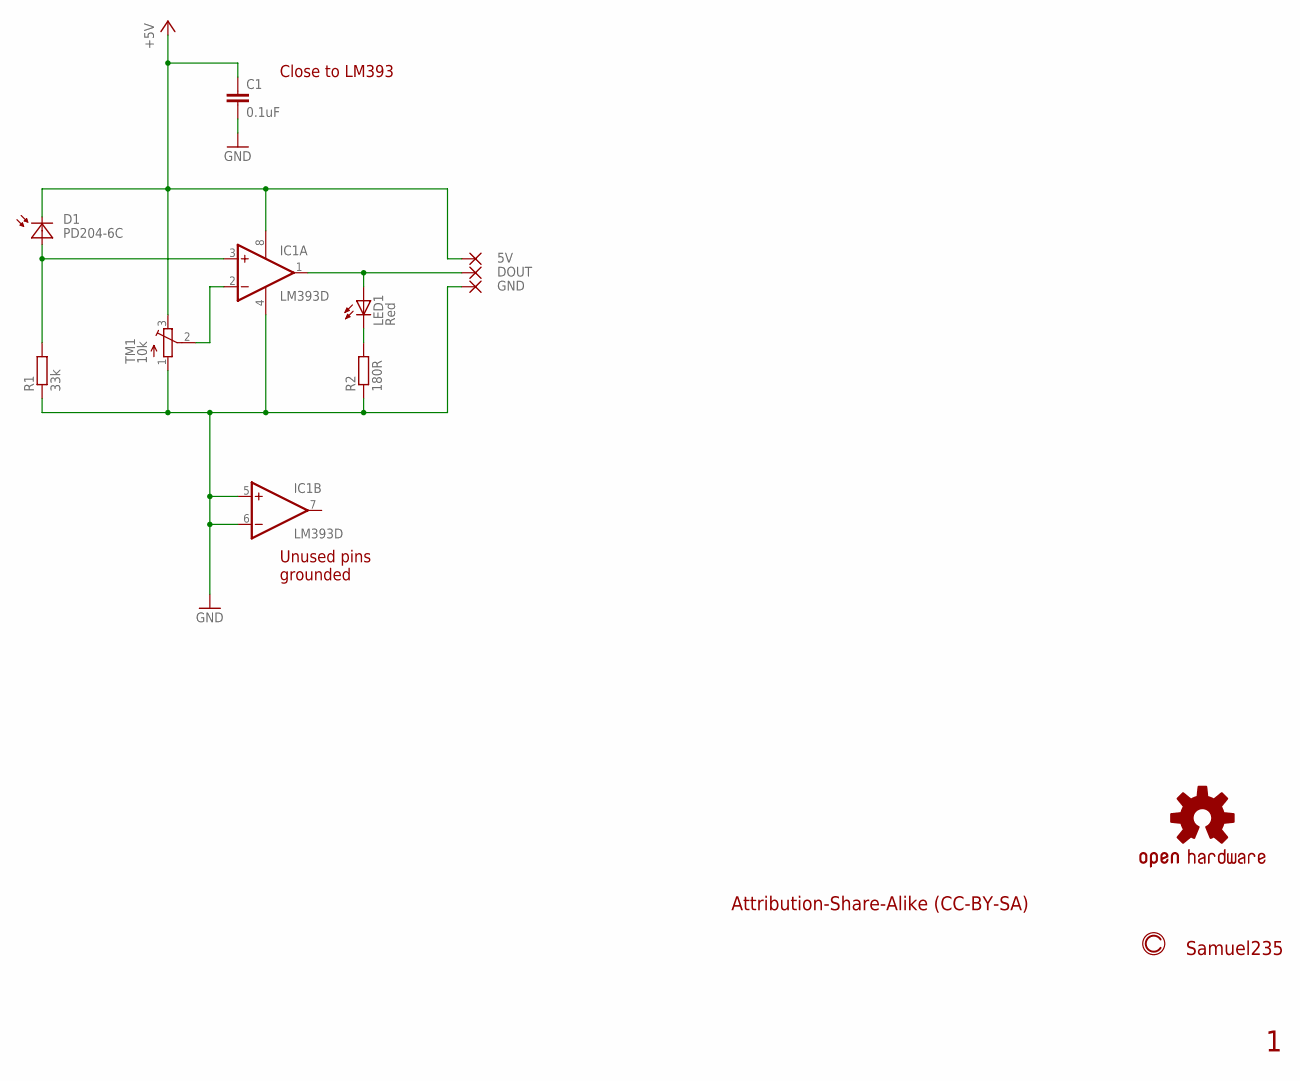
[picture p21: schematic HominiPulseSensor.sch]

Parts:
5V: SMD2; SMD1,27-2,54
C1: 0.1uF; C0603
D1: PD204-6C; 3MM-PTH
DOUT: SMD2; SMD1,27-2,54
GND: SMD2; SMD1,27-2,54
IC1: LM393D; SO08
LED1: Red; LED3MM
LOGO1: OSHW-LOGOS; OSHW-LOGO-S
R1: 33k; R0603
R2: 180R; R0603
TM1: 10k; TC33X

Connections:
+5V: 5V.1, C1.1, D1.C, IC1.8 (V+), TM1.3 (E)
GND: C1.2, GND.1, IC1.4 (V-), IC1.5 (+IN), IC1.6 (-IN), R1.1, R2.1, TM1.1 (A)
unnamed: D1.A, IC1.3 (+IN), R1.2
unnamed: IC1.2 (-IN), TM1.2 (S)
unnamed: DOUT.1, IC1.1 (OUT), LED1.A
unnamed: LED1.K (C), R2.2

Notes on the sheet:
Samuel235
Attribution-Share-Alike (CC-BY-SA)
Close to LM393
Unused pins grounded

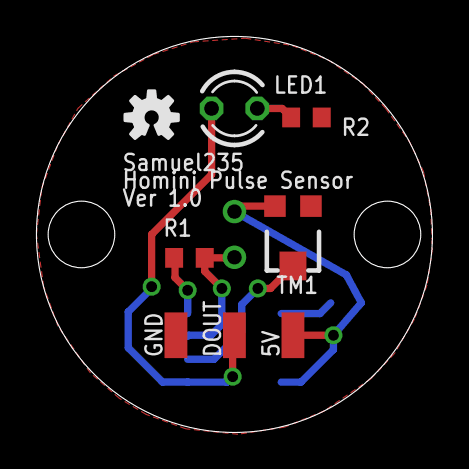
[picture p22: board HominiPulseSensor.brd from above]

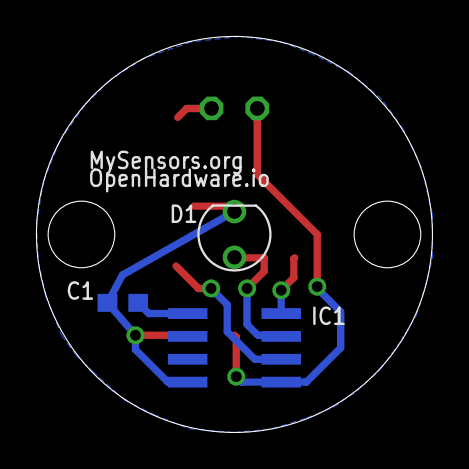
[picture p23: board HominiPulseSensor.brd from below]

Board: 2 copper layers, 22.0 x 22.0 mm, 11 parts (3 on the bottom side), 6 nets.

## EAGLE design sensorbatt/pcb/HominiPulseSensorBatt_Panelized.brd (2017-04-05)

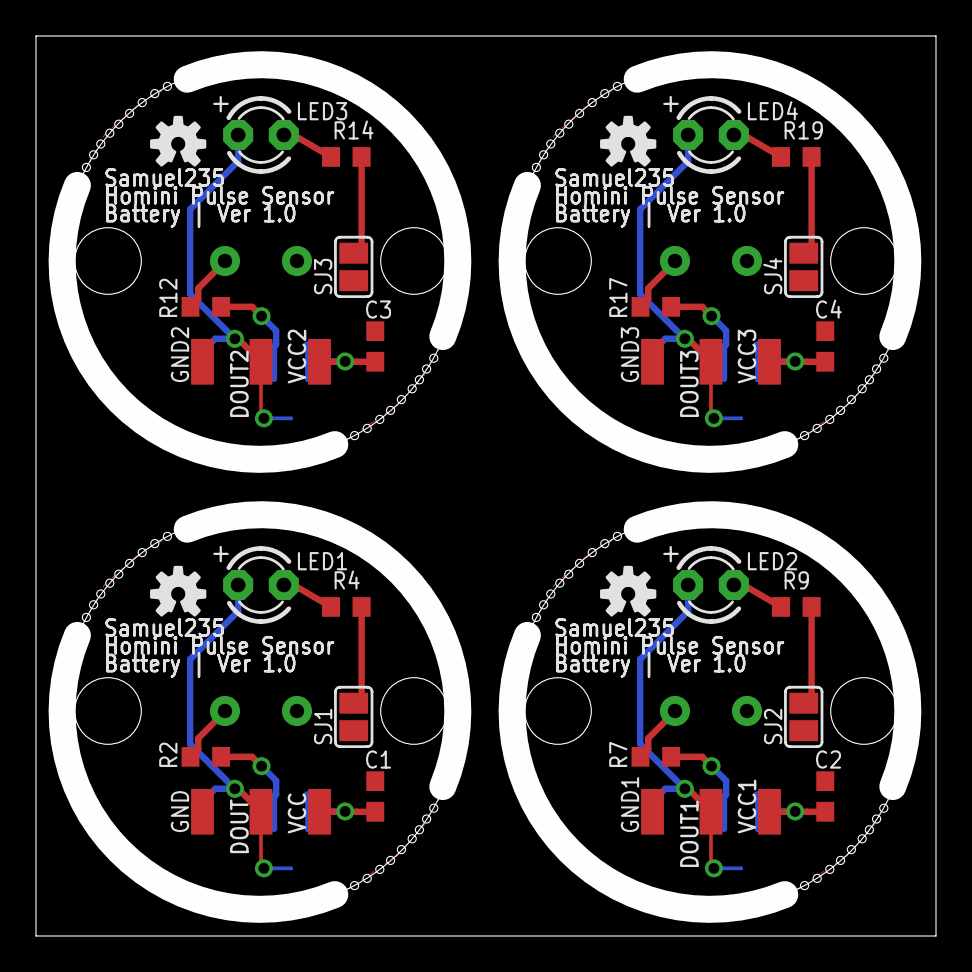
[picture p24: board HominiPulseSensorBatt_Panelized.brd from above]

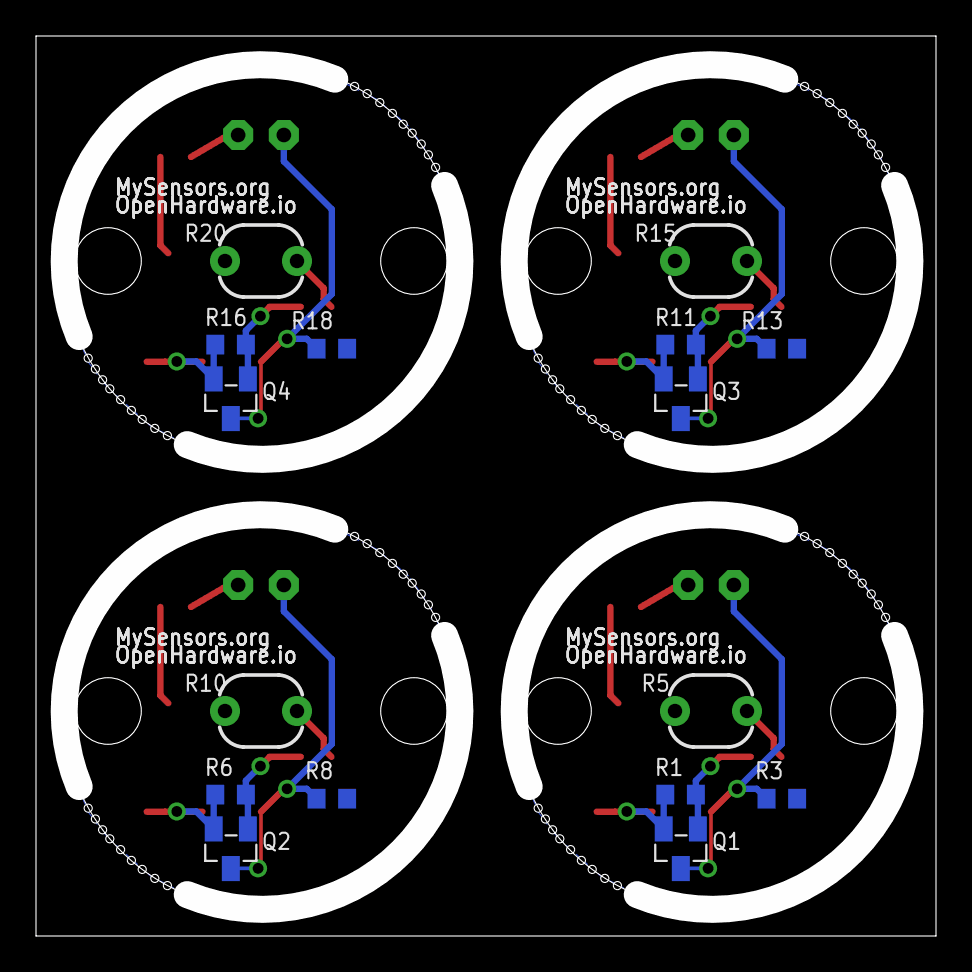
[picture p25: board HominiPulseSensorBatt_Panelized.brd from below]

Board: 2 copper layers, 50.0 x 50.0 mm, 52 parts (16 on the bottom side), 28 nets.

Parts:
C1, C2, C3, C4: 0.1uF; C0603
DOUT, DOUT1, DOUT2, DOUT3: SMD1,27-2,54
GND, GND1, GND2, GND3: SMD1,27-2,54
LED1, LED2, LED3, LED4: Red; LED3MM
LOGO1, LOGO2, LOGO3, LOGO4: OSHW-LOGOS; OSHW-LOGO-S
Q1, Q2, Q3, Q4: BS250SMD; SOT23
R1, R6, R11, R16: 330K; R0603
R2, R7, R12, R17: 100K; R0603
R3, R8, R13, R18: 470K; R0603
R4, R9, R14, R19: 1K5; R0603
R5, R10, R15, R20: 5549-LDR; LDR-PTH
SJ1, SJ2, SJ3, SJ4: SJ
VCC, VCC1, VCC2, VCC3: SMD1,27-2,54

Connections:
GND: C1.2, GND.1, R3.1, R5.1, SJ1.1
GND1: C2.2, GND1.1, R8.1, R10.1, SJ2.1
GND2: C3.2, GND2.1, R13.1, R15.1, SJ3.1
GND3: C4.2, GND3.1, R18.1, R20.1, SJ4.1
unnamed: Q1.1, R1.1, R2.2
unnamed: R2.1, R5.2
unnamed: DOUT.1, LED1.A, Q1.3, R3.2
unnamed: R4.1, SJ1.2
unnamed: LED1.K, R4.2
unnamed: Q2.1, R6.1, R7.2
unnamed: R7.1, R10.2
unnamed: DOUT1.1, LED2.A, Q2.3, R8.2
unnamed: R9.1, SJ2.2
unnamed: LED2.K, R9.2
unnamed: Q3.1, R11.1, R12.2
unnamed: R12.1, R15.2
unnamed: DOUT2.1, LED3.A, Q3.3, R13.2
unnamed: R14.1, SJ3.2
unnamed: LED3.K, R14.2
unnamed: Q4.1, R16.1, R17.2
unnamed: R17.1, R20.2
unnamed: DOUT3.1, LED4.A, Q4.3, R18.2
unnamed: R19.1, SJ4.2
unnamed: LED4.K, R19.2
VCC: C1.1, Q1.2, R1.2, VCC.1
VCC1: C2.1, Q2.2, R6.2, VCC1.1
VCC2: C3.1, Q3.2, R11.2, VCC2.1
VCC3: C4.1, Q4.2, R16.2, VCC3.1

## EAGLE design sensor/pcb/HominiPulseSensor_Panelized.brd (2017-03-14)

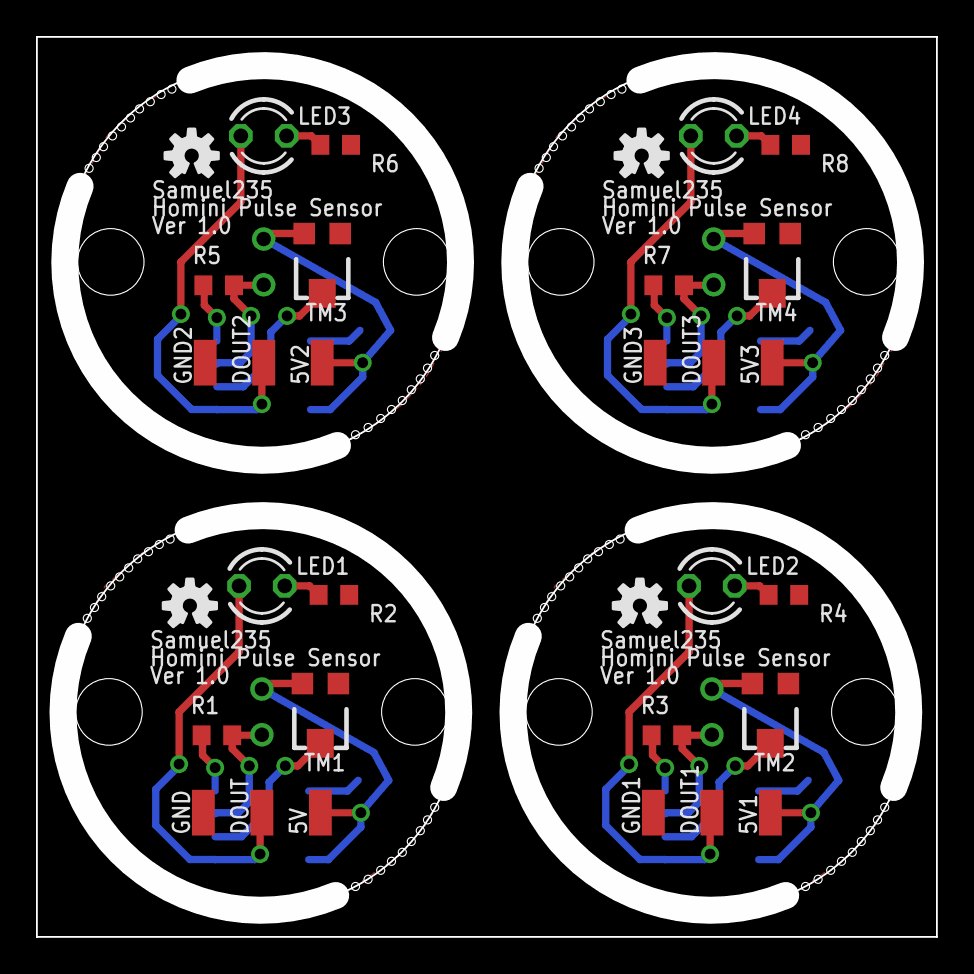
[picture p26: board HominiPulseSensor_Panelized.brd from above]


Board: 2 copper layers, 50.0 x 50.0 mm, 44 parts (12 on the bottom side), 24 nets.

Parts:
5V, 5V1, 5V2, 5V3: SMD1,27-2,54
C1, C2, C3, C4: 0.1uF; C0603
D1, D2, D3, D4: PD204-6C; 3MM-PTH
DOUT, DOUT1, DOUT2, DOUT3: SMD1,27-2,54
GND, GND1, GND2, GND3: SMD1,27-2,54
IC1, IC2, IC3, IC4: LM393D; SO08
LED1, LED2, LED3, LED4: Red; LED3MM
LOGO1, LOGO2, LOGO3, LOGO4: OSHW-LOGOS; OSHW-LOGO-S
R1, R3, R5, R7: 33k; R0603
R2, R4, R6, R8: 180R; R0603
TM1, TM2, TM3, TM4: 10k; TC33X

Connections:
+5V: 5V.1, C1.1, D1.C, IC1.8, TM1.3
+5V1: 5V1.1, C2.1, D2.C, IC2.8, TM2.3
+5V2: 5V2.1, C3.1, D3.C, IC3.8, TM3.3
+5V3: 5V3.1, C4.1, D4.C, IC4.8, TM4.3
GND: C1.2, GND.1, IC1.4, IC1.5, IC1.6, R1.1, R2.1, TM1.1
GND1: C2.2, GND1.1, IC2.4, IC2.5, IC2.6, R3.1, R4.1, TM2.1
GND2: C3.2, GND2.1, IC3.4, IC3.5, IC3.6, R5.1, R6.1, TM3.1
GND3: C4.2, GND3.1, IC4.4, IC4.5, IC4.6, R7.1, R8.1, TM4.1
unnamed: D1.A, IC1.3, R1.2
unnamed: IC1.2, TM1.2
unnamed: D2.A, IC2.3, R3.2
unnamed: DOUT.1, IC1.1, LED1.A
unnamed: LED1.K, R2.2
unnamed: DOUT1.1, IC2.1, LED2.A
unnamed: LED2.K, R4.2
unnamed: IC2.2, TM2.2
unnamed: D3.A, IC3.3, R5.2
unnamed: DOUT2.1, IC3.1, LED3.A
unnamed: LED3.K, R6.2
unnamed: IC3.2, TM3.2
unnamed: D4.A, IC4.3, R7.2
unnamed: DOUT3.1, IC4.1, LED4.A
unnamed: LED4.K, R8.2
unnamed: IC4.2, TM4.2

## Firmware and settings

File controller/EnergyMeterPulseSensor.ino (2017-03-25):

/**
 * The MySensors Arduino library handles the wireless radio link and protocol
 * between your home built sensors/actuators and HA controller of choice.
 * The sensors forms a self healing radio network with optional repeaters. Each
 * repeater and gateway builds a routing tables in EEPROM which keeps track of the
 * network topology allowing messages to be routed to nodes.
 *
 * Created by Henrik Ekblad <henrik.ekblad@mysensors.org>
 * Copyright (C) 2013-2015 Sensnology AB
 * Full contributor list: https://github.com/mysensors/Arduino/graphs/contributors
 *
 * Documentation: http://www.mysensors.org
 * Support Forum: http://forum.mysensors.org
 *
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
 *******************************
 *
 * REVISION HISTORY
 * Version 1.0 - Henrik EKblad
 *
 * DESCRIPTION
 * This sketch provides an example how to implement a distance sensor using HC-SR04
 * Use this sensor to measure KWH and Watt of your house meeter
 * You need to set the correct pulsefactor of your meeter (blinks per KWH).
 * The sensor starts by fetching current KWH value from gateway.
 * Reports both KWH and Watt back to gateway.
 *
 * Unfortunately millis() won't increment when the Arduino is in
 * sleepmode. So we cannot make this sensor sleep if we also want
 * to calculate/report watt-number.
 * http://www.mysensors.org/build/pulse_power
 */

// Enable debug prints
#define MY_DEBUG

// Enable and select radio type attached
#define MY_RADIO_NRF24
//#define MY_RADIO_RFM69

#include <MySensors.h>

#define DIGITAL_INPUT_SENSOR 3  // The digital input you attached your light sensor.  (Only 2 and 3 generates interrupt!)
#define PULSE_FACTOR 1000       // Nummber of blinks per KWH of your meeter
#define SLEEP_MODE false        // Watt-value can only be reported when sleep mode is false.
#define MAX_WATT 10000          // Max watt value to report. This filetrs outliers.
#define CHILD_ID 1              // Id of the sensor child

unsigned long SEND_FREQUENCY =
    20000; // Minimum time between send (in milliseconds). We don't wnat to spam the gateway.
double ppwh = ((double)PULSE_FACTOR)/1000; // Pulses per watt hour
bool pcReceived = false;
volatile unsigned long pulseCount = 0;
volatile unsigned long lastBlink = 0;
volatile unsigned long watt = 0;
unsigned long oldPulseCount = 0;
unsigned long oldWatt = 0;
double oldKwh;
unsigned long lastSend;
MyMessage wattMsg(CHILD_ID,V_WATT);
MyMessage kwhMsg(CHILD_ID,V_KWH);
MyMessage pcMsg(CHILD_ID,V_VAR1);


void setup()
{
    // Fetch last known pulse count value from gw
    request(CHILD_ID, V_VAR1);

    // Use the internal pullup to be able to hook up this sketch directly to an energy meter with S0 output
    // If no pullup is used, the reported usage will be too high because of the floating pin
    pinMode(DIGITAL_INPUT_SENSOR,INPUT_PULLUP);

    attachInterrupt(digitalPinToInterrupt(DIGITAL_INPUT_SENSOR), onPulse, RISING);
    lastSend=millis();
}

void presentation()
{
    // Send the sketch version information to the gateway and Controller
    sendSketchInfo("Energy Meter", "1.0");

    // Register this device as power sensor
    present(CHILD_ID, S_POWER);
}

void loop()
{
    unsigned long now = millis();
    // Only send values at a maximum frequency or woken up from sleep
    bool sendTime = now - lastSend > SEND_FREQUENCY;
    if (pcReceived && (SLEEP_MODE || sendTime)) {
        // New watt value has been calculated
        if (!SLEEP_MODE && watt != oldWatt) {
            // Check that we dont get unresonable large watt value.
            // could hapen when long wraps or false interrupt triggered
            if (watt<((unsigned long)MAX_WATT)) {
                send(wattMsg.set(watt));  // Send watt value to gw
            }
            Serial.print("Watt:");
            Serial.println(watt);
            oldWatt = watt;
        }

        // Pulse cout has changed
        if (pulseCount != oldPulseCount) {
            send(pcMsg.set(pulseCount));  // Send pulse count value to gw
            double kwh = ((double)pulseCount/((double)PULSE_FACTOR));
            oldPulseCount = pulseCount;
            if (kwh != oldKwh) {
                send(kwhMsg.set(kwh, 4));  // Send kwh value to gw
                oldKwh = kwh;
            }
        }
        lastSend = now;
    } else if (sendTime && !pcReceived) {
        // No count received. Try requesting it again
        request(CHILD_ID, V_VAR1);
        lastSend=now;
    }

    if (SLEEP_MODE) {
        sleep(SEND_FREQUENCY);
    }
}

void receive(const MyMessage &message)
{
    if (message.type==V_VAR1) {
        pulseCount = oldPulseCount = message.getLong();
        Serial.print("Received last pulse count from gw:");
        Serial.println(pulseCount);
        pcReceived = true;
    }
}

void onPulse()
{
    if (!SLEEP_MODE) {
        unsigned long newBlink = micros();
        unsigned long interval = newBlink-lastBlink;
        if (interval<10000L) { // Sometimes we get interrupt on RISING
            return;
        }
        watt = (3600000000.0 /interval) / ppwh;
        lastBlink = newBlink;
    }
    pulseCount++;
}

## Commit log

2017-03-25 Update README.md
    Updated some information regarding battery powered devices
2017-03-25 Improved Folder Structure
    Created new folder structure for better navigation
    [Bottom.STL, HominiPulseSensor.brd, HominiPulseSensor.sch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]
2017-04-05 Added files
    Added battery sensor files
    Added datasheets for controller board
    Removed gerber zip file - Individual files remain in git
    [HominiPulseSensorBatt.brd, HominiPulseSensorBatt.sch, HominiPulseSensorBattBOM.csv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]
2017-04-06 Added Files
    Controller gerber & BOM files
    Sensor BOM files
    Sensorbatt BOM files and PCB images
    [HominiPulseSensorBatt.skp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]
2017-04-10 Files added
    Added some gerbers
    Modified existing gerbers
    [HominiPulseSensor.GBL, HominiPulseSensor.GBO, HominiPulseSensor.GBS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]
2017-04-10 Sketchup files added
    [HominiPulseSensor.skp, HominiPulseSensorBatt.skp]
2017-04-11 Files added
    Solidworks file - Enclosure
    Enclosure render images
    [HominiPulseSensorControllerEnclosure.SLDPRT]
2017-04-11 File Update
    Solidworks File - Controller
    [HominiPulseSensorControllerEnclosure.SLDPRT]
2017-05-08 Additional files & updates
    Modified some controller CAD files
    Added some controller STL files
    Modified some sensor CAD files
    Added some sensor STL files
    Modified some sensor battery version CAD files
    Added some sensor battery version STL files
    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
    [Bottom.STL, HominiPulseSensorControllerEnclosure.SLDPRT, HominiPulseSensorControllerEnclosure.STL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]

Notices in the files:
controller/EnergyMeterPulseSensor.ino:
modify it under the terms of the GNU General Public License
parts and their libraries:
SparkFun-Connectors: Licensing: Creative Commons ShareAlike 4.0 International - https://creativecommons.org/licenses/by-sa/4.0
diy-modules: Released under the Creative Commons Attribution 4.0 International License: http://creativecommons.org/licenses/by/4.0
